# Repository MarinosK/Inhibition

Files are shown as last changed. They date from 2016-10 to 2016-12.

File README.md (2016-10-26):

### Inhibition ###

Installation | Workshop (c) 2016
by Marinos Koutsomichalis <marinos@marinoskoutsomichalis.com>

Code and hardware designs are distributed under the Attribution-NonCommercial-ShareAlike 3.0 Unported Creative Commons Licence (details here: http://creativecommons.org/licenses/by-nc-sa/3.0/deed.en_US).

> EVERYTHING IN THIS BUNDLE IS DISTRIBUTED AS IS WITH NO GUARANTEE OF FUNCTIONALITY OR RELEVANCE TO THIRD PARTY PROJECTS - THE DEVELOPER IS NOT TO BE HELD RESPONSIBLE FOR PERSONAL INJURIES, HARDWARE, FINANCIAL, OR ANY OTHER LOSSES AND IN GENERAL FOR ANY MISFORTUNATE EVENT CAUSED BY THE DESCRIBED SOFTWARE/HARDWARE OR IN THE PROCESS OF ATTEMPTING TO IMPLEMENT IT. IF YOU DON'T AGREE WITH THE AFOREMENTIONED YOUR ARE NOT ALLOWED TO USE THE MATERIAL PROVIDED HEREIN

# This bundle comprises #

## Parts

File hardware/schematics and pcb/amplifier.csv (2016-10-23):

Reference | Value | Footprint | Datasheet
R20 | 15K | Resistors_ThroughHole:Resistor_Horizontal_RM10mm
R19 | 10K | Resistors_ThroughHole:Resistor_Horizontal_RM10mm
C24 | .01μ | Capacitors_ThroughHole:C_Disc_D3_P2.5
C23 | .01μ | Capacitors_ThroughHole:C_Disc_D3_P2.5
C25 | 1n | Capacitors_ThroughHole:C_Disc_D3_P2.5
U4 | CA3140 | Housings_DIP:DIP-8_W7.62mm
C27 | 1μ | Capacitors_ThroughHole:C_Disc_D3_P2.5
C26 | 1μ | Capacitors_ThroughHole:C_Disc_D3_P2.5
C29 | 10μ | Capacitors_ThroughHole:C_Disc_D3_P2.5
C28 | 10μ | Capacitors_ThroughHole:C_Disc_D3_P2.5
R21 | 1K | Resistors_ThroughHole:Resistor_Horizontal_RM10mm
P7 | CONN_01X20 | Pin_Headers:Pin_Header_Straight_1x20
P6 | CONN_01X20 | Pin_Headers:Pin_Header_Straight_1x20
P4 | CONN_01X20 | Pin_Headers:Pin_Header_Straight_1x20
J1 | JACK_2P | Connect:BARREL_JACK
SW1 | Switch_DPST | Connect:Switch_LED
R5 | 100 | Resistors_ThroughHole:Resistor_Horizontal_RM10mm
R6 | 100 | Resistors_ThroughHole:Resistor_Horizontal_RM10mm
U1 | AD620 | Housings_DIP:DIP-8_W7.62mm
C7 | 0.01μ | Capacitors_ThroughHole:C_Disc_D3_P2.5
C8 | 0.33μ | Capacitors_ThroughHole:C_Disc_D3_P2.5
C11 | 0.01μ | Capacitors_ThroughHole:C_Disc_D3_P2.5
C12 | 0.33μ | Capacitors_ThroughHole:C_Disc_D3_P2.5
C9 | 0.01μ | Capacitors_ThroughHole:C_Disc_D3_P2.5
C5 | 0.01μ | Capacitors_ThroughHole:C_Disc_D3_P2.5
C10 | 0.33μ | Capacitors_ThroughHole:C_Disc_D3_P2.5
C6 | 0.33μ | Capacitors_ThroughHole:C_Disc_D3_P2.5
U2 | LM324 | Housings_DIP:DIP-14_W7.62mm
R4 | 100K | Resistors_ThroughHole:Resistor_Horizontal_RM10mm
C4 | 1n | Capacitors_ThroughHole:C_Rect_L7_W6_P5
C13 | 10μ | Capacitors_ThroughHole:C_Disc_D3_P2.5
R9 | 10K | Resistors_ThroughHole:Resistor_Horizontal_RM10mm
R12 | 470K | Resistors_ThroughHole:Resistor_Horizontal_RM10mm
R10 | 10K | Resistors_ThroughHole:Resistor_Horizontal_RM10mm
R14 | 10K | Resistors_ThroughHole:Resistor_Horizontal_RM10mm
C21 | 0.82μ | Capacitors_ThroughHole:C_Rect_L7_W6_P5
C17 | 0.47μ | Capacitors_ThroughHole:C_Rect_L7_W6_P5
R15 | 10K | Resistors_ThroughHole:Resistor_Horizontal_RM10mm
R17 | 470K | Resistors_ThroughHole:Resistor_Horizontal_RM10mm
C22 | 10μ | Capacitors_ThroughHole:C_Disc_D3_P2.5
R1 | 100K | Resistors_ThroughHole:Resistor_Horizontal_RM10mm
C3 | 1n | Capacitors_ThroughHole:C_Rect_L7_W6_P5
C2 | 0.01μ | Capacitors_ThroughHole:C_Rect_L7_W6_P5
R3 | 15M | Resistors_ThroughHole:Resistor_Horizontal_RM10mm
C1 | 0.01μ | Capacitors_ThroughHole:C_Rect_L7_W6_P5
R2 | 15M | Resistors_ThroughHole:Resistor_Horizontal_RM10mm
R16 | 10K | Resistors_ThroughHole:Resistor_Horizontal_RM10mm
R7 | 10K | Resistors_ThroughHole:Resistor_Horizontal_RM10mm
C16 | 0.82μ | Capacitors_ThroughHole:C_Rect_L7_W6_P5
C15 | 0.47μ | Capacitors_ThroughHole:C_Rect_L7_W6_P5
R11 | 10K | Resistors_ThroughHole:Resistor_Horizontal_RM10mm
R13 | 470K | Resistors_ThroughHole:Resistor_Horizontal_RM10mm
R8 | 10K | Resistors_ThroughHole:Resistor_Horizontal_RM10mm
C18 | 10μ | Capacitors_ThroughHole:C_Disc_D3_P2.5
C14 | 10μ | Capacitors_ThroughHole:C_Disc_D3_P2.5
P1 | CONN_01X03 | Pin_Headers:Pin_Header_Straight_1x03
RV1 | POT | Pin_Headers:Pin_Header_Angled_1x03
C19 | 0.01μ | Capacitors_ThroughHole:C_Disc_D3_P2.5
C20 | 0.33μ | Capacitors_ThroughHole:C_Disc_D3_P2.5
P8 | CONN_01X02 | Pin_Headers:Pin_Header_Straight_1x02
U3 | MCP3008 | Housings_DIP:DIP-16_W7.62mm
R18 | 220 | Resistors_ThroughHole:Resistor_Horizontal_RM10mm
P3 | CONN_01X07 | Pin_Headers:Pin_Header_Straight_1x07
P2 | CONN_01X07 | Pin_Headers:Pin_Header_Straight_1x07
P5 | CONN_01X20 | Pin_Headers:Pin_Header_Straight_1x20
R22 | 1K | Resistors_ThroughHole:Resistor_Horizontal_RM10mm

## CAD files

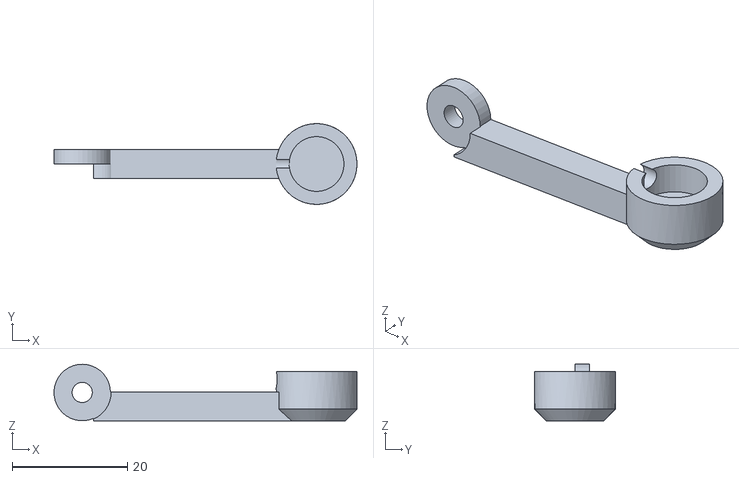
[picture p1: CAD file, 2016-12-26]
hardware/3d models/EEG Terminal Connectors/05.terminal.STL
52.5 x 14.0 x 9.79

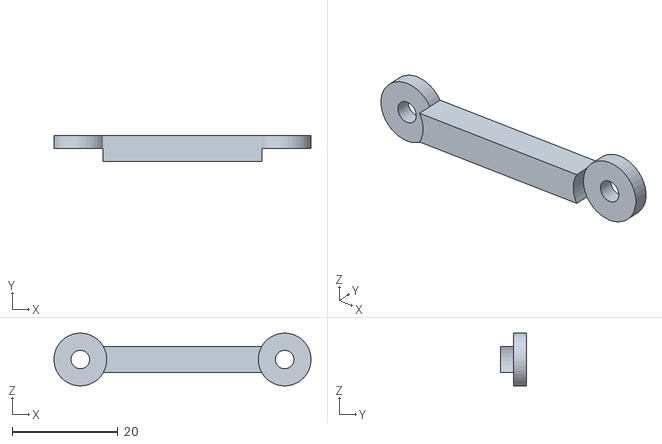
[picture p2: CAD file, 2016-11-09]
hardware/3d models/EEG Terminal Connectors/04.short_arm.STL
48.6 x 5.00 x 9.99

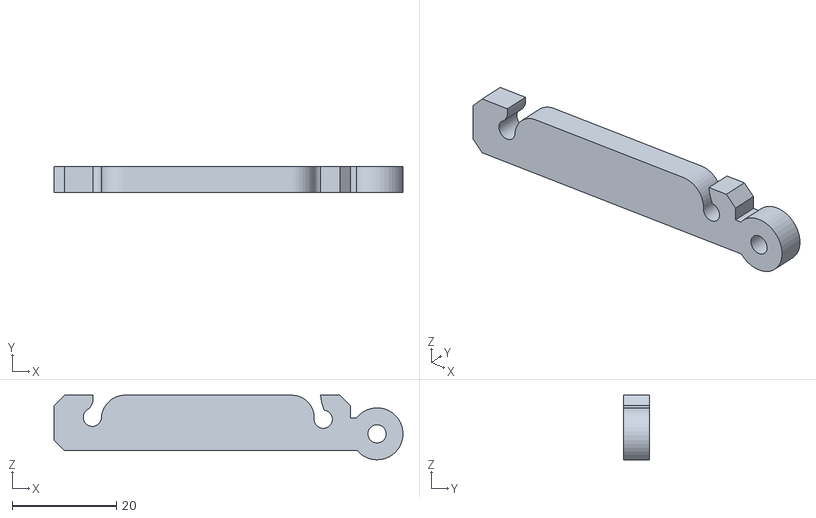
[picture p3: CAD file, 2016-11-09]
hardware/3d models/EEG Terminal Connectors/07.side_arm.STL
67.1 x 5.00 x 12.4

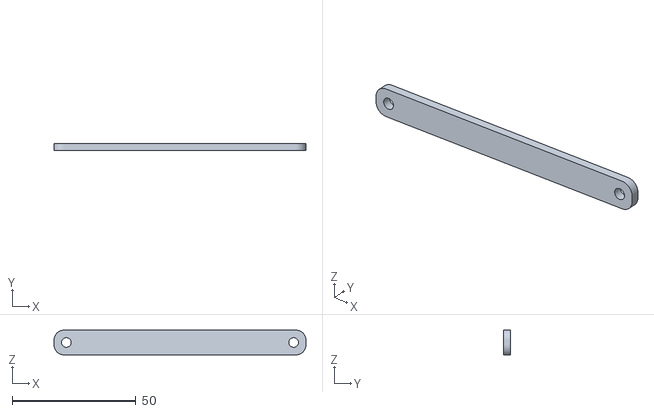
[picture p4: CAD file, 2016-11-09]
hardware/3d models/EEG Terminal Connectors/06.bridge.STL
102.0 x 3.00 x 10.0

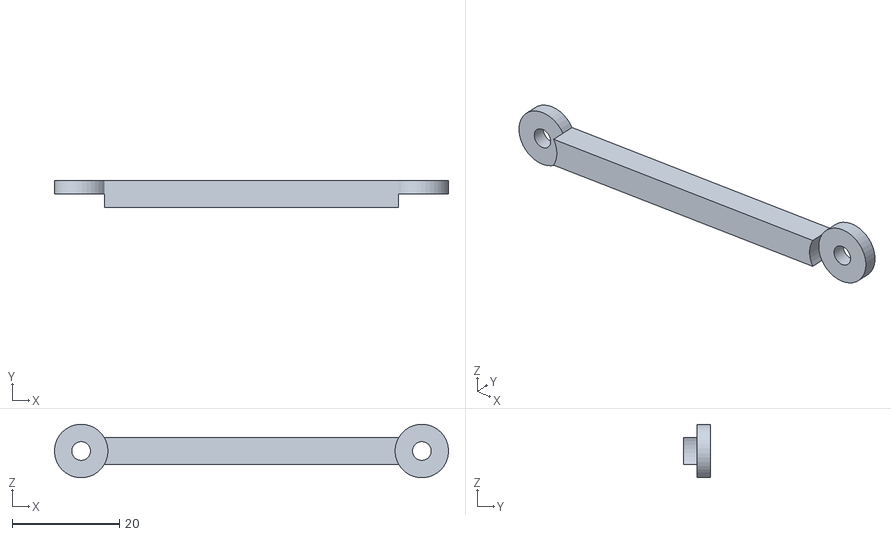
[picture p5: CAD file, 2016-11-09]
hardware/3d models/EEG Terminal Connectors/03.long_arm.STL
73.6 x 5.00 x 9.99

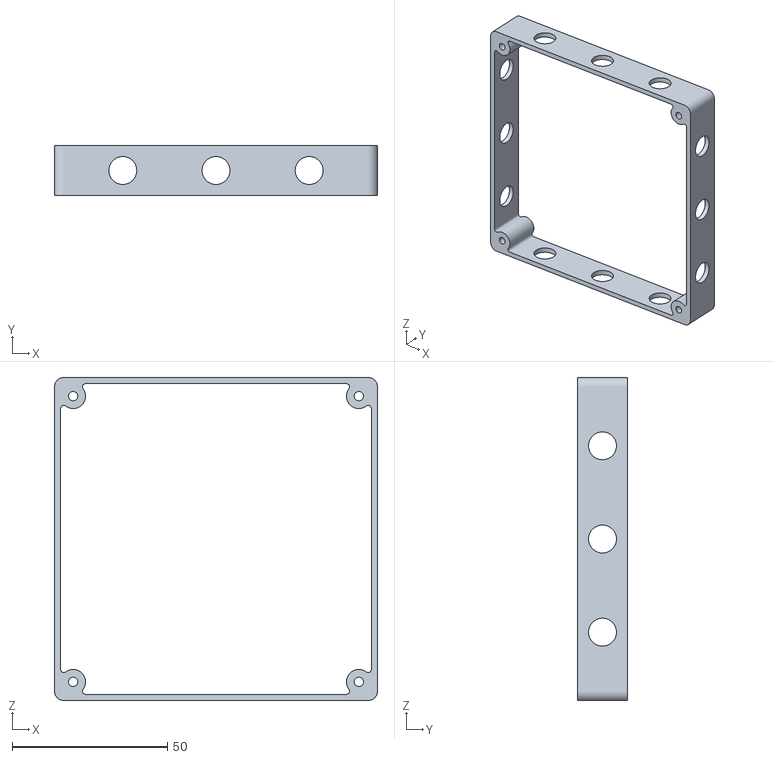
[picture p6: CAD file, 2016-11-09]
hardware/3d models/EEG Terminal Connectors/01.spacer.STL
104.0 x 16.0 x 104.0

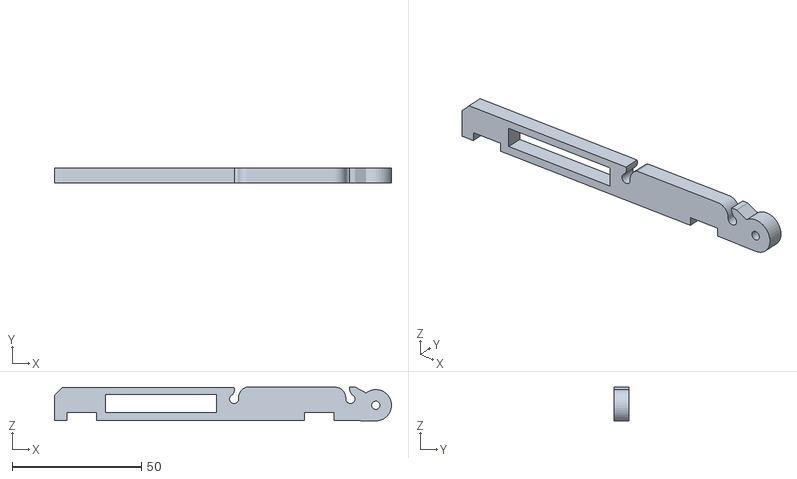
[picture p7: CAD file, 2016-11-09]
hardware/3d models/EEG Terminal Connectors/02.middle_arm.STL
130.5 x 6.00 x 13.1

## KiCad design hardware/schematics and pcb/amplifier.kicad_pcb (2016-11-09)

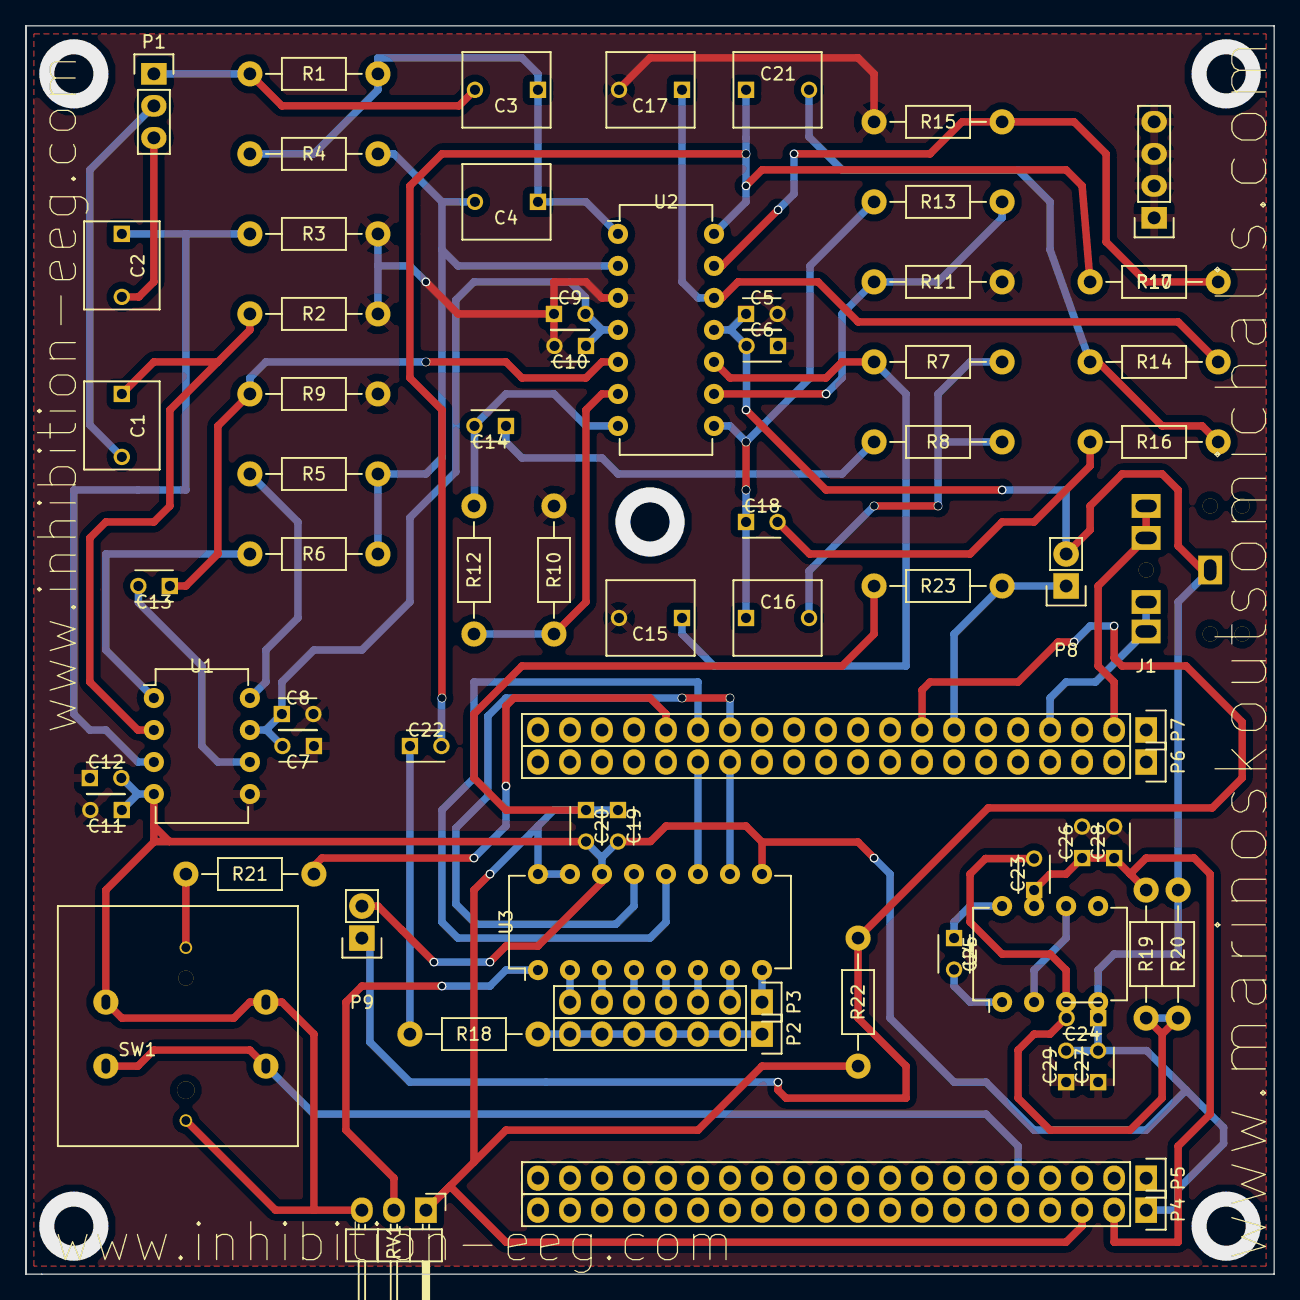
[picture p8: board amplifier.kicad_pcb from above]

Board: 2 copper layers, 99.1 x 99.1 mm, 69 parts (0 on the bottom side), 51 nets.

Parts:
C1, C2: 0.01μ; C_Rect_L7_W6_P5
C3, C4: 1n; C_Rect_L7_W6_P5
C5, C7, C9, C11, C19: 0.01μ; C_Disc_D3_P2.5
C6, C8, C10, C12, C20: 0.33μ; C_Disc_D3_P2.5
C13, C14, C18, C22, C28, C29: 10μ; C_Disc_D3_P2.5
C15, C17: 0.47μ; C_Rect_L7_W6_P5
C16, C21: 0.82μ; C_Rect_L7_W6_P5
C23, C24: .01μ; C_Disc_D3_P2.5
C25: 1n; C_Disc_D3_P2.5
C26, C27: 1μ; C_Disc_D3_P2.5
J1: JACK_2P; BARREL_JACK
P1: CONN_01X03; Pin_Header_Straight_1x03
P2, P3: CONN_01X07; Pin_Header_Straight_1x07
P4, P5, P6, P7: CONN_01X20; Pin_Header_Straight_1x20
P8, P9: CONN_01X02; Pin_Header_Straight_1x02
P10: CONN_01X04; Pin_Header_Straight_1x04
R1, R4: 100K; Resistor_Horizontal_RM10mm
R2, R3: 15M; Resistor_Horizontal_RM10mm
R5, R6, R18: 220; Resistor_Horizontal_RM10mm
R7, R8, R9, R10, R11, R14, R15, R16, R20: 10K; Resistor_Horizontal_RM10mm
R12: 890K; Resistor_Horizontal_RM10mm
R13: 1.8; Resistor_Horizontal_RM10mm
R17: .6; Resistor_Horizontal_RM10mm
R19: 15K; Resistor_Horizontal_RM10mm
R21: 10; Resistor_Horizontal_RM10mm
R22, R23: 1K; Resistor_Horizontal_RM10mm
RV1: POT; Pin_Header_Angled_1x03
SW1: Switch_DPST; Switch_LED
U1: AD620; DIP-8_W7.62mm
U2: LM324; DIP-14_W7.62mm
U3: MCP3008; DIP-16_W7.62mm
U4: CA3140; DIP-8_W7.62mm

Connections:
GND: C5.2, C6.1, C7.1, C8.2, C9.1, C10.2, C11.2, C12.1, C15.2, C17.2, C26.2, C27.1, C28.2, C29.1, P10.1, P10.2, P10.3, P10.4, R2.2, R3.2, R9.2, R10.2, R11.2, R15.2, U1.5, U2.3, U4.2, U4.6
unnamed: C1.1, R2.1, U1.2
unnamed: C1.2, P1.2
unnamed: C2.1, R3.1, U1.3
unnamed: C2.2, P1.3
unnamed: C3.1, C4.1, R1.1, R4.1, U2.1
unnamed: C3.2, P1.1, R1.2
unnamed: C4.2, R4.2, R5.2, R6.1, U2.2
unnamed: C13.1, R9.1, U2.5
unnamed: C13.2, U1.6
unnamed: C14.1, R8.2
unnamed: C14.2, R12.1, U2.7
unnamed: C15.1, R7.1, U2.10
unnamed: C16.1, C18.1, R13.1, U2.8
unnamed: C16.2, R7.2, R8.1
unnamed: C17.1, R14.2, U2.12
unnamed: C18.2, R16.2
unnamed: C19.1, C20.1, P4.3, R22.2, R23.2, RV1.1, U3.15, U3.16
unnamed: C21.1, C22.2, R17.1, U2.14
unnamed: C21.2, R14.1, R16.1
unnamed: C22.1, R18.1
unnamed: C23.2, C24.2, R19.2, R20.1, U4.3
unnamed: C25.1, U4.8
unnamed: C25.2, U4.1
unnamed: J1.1, P7.4
unnamed: J1.3, P7.2
unnamed: P2.1, P2.2, P2.3, P2.4, P2.5, P2.6, P2.7, R18.2
unnamed: P3.1, U3.8
unnamed: P3.2, U3.7
unnamed: P3.3, U3.6
unnamed: P3.4, U3.5
unnamed: P3.5, U3.4
unnamed: P3.6, U3.3
unnamed: P3.7, U3.2
unnamed: P5.5, SW1.1, SW1.3
unnamed: P6.14, U3.10
unnamed: P6.15, U3.11
unnamed: P7.7, P8.1, R23.1
unnamed: P7.8, P9.1, R22.1
unnamed: P7.14, U3.13
unnamed: P7.15, U3.12
unnamed: P7.16, R21.2
unnamed: R5.1, U1.8
unnamed: R6.2, U1.1
unnamed: R10.1, R12.2, U2.6
unnamed: R11.1, R13.2, U2.9
unnamed: R15.1, R17.2, U2.13
unnamed: R21.1, SW1.5
unnamed: RV1.2, U3.1
VCC: C7.2, C8.1, C9.2, C10.1, C23.1, C26.1, C28.1, P4.2, R19.1, U1.7, U2.4, U4.7
VEE: C5.1, C6.2, C11.1, C12.2, C19.2, C20.2, C24.1, C27.2, C29.2, J1.2, P4.1, P8.2, P9.2, R20.2, RV1.3, SW1.2, SW1.4, SW1.6, U1.4, U2.11, U3.9, U3.14, U4.4

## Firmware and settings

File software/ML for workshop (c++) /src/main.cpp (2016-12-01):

/*
 * by Marinos Koutsomichalis (me@marinoskoutsomichalis.com)
 * Heraklion, 10.2016
 * this program implements a neural network to use with the main SC code
 */

#include <fann.h>
#include <iostream>
#include <stdexcept>
#include <string>
#include <cstring>

// settings
const float desired_error = (const float) 0.01;
const unsigned int max_epochs = 10000;
const unsigned int epochs_between_reports = 100;

int main(int argc, char *argv[]) {
  try {
    if ( std::string(argv[1]) == "create") { // e.g. neural_net create
      unsigned int layers[5] = {8, 8, 24, 16, 8}; // the layers of the network
      struct fann *ann {fann_create_shortcut_array(5, layers)};
      fann_set_activation_function_hidden(ann, FANN_SIGMOID_SYMMETRIC);
      fann_set_activation_function_output(ann, FANN_SIGMOID_SYMMETRIC);
      fann_randomize_weights(ann,0,1);
      fann_save(ann, "network.net");
      fann_destroy(ann);
    } else if ( std::string(argv[1]) == "train") { // e.g. neural_net train data_file
      struct fann *ann  {fann_create_from_file("network.net")};
      fann_train_on_file(ann, argv[2], max_epochs, epochs_between_reports, desired_error);
      fann_save(ann, "network.net");
      fann_destroy(ann);
    } else if ( std::string(argv[1]) == "use") { // e.g. neural_net use 1 0 1 .. 1 (all the 16 features should be the input)
      struct fann *ann {fann_create_from_file("network.net")};
      fann_type input[8];
      for (int i=0; i<8; i++)
	input[i] = std::atof(argv[i+2]);
      fann_type *calc_out {fann_run(ann, input)};
      for (int i=0; i<8; i++)
	std::cout << calc_out[i] << ", ";
      std::cout << std::endl;
      fann_destroy(ann);
    }
    return 0;
  }
  catch (const std::runtime_error& e) {
    std::cerr << e.what() << std::endl;
    return 1;
  }
  catch (const std::exception& e) {
    std::cerr << e.what() << std::endl;
    return 2;
  }
  catch (...) {
    std::cerr << "uknown exception" << std::endl;
    return 3;
  }
}

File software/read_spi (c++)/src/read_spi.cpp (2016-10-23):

/*
 * by Marinos Koutsomichalis (me@marinoskoutsomichalis.com)
 * Heraklion, 10.2009
 * this program reads 2channels of 5seconds of eeg audio from a MPC3008 chip
 * and stores the output into an audio file
 */

#include "read_spi.h"

// static uint8_t mode {};
static uint16_t delay {};
static std::uint8_t bits {8};
static std::uint32_t speed {500000};
static const char* DEVICE {"/dev/spidev32766.0"};


int read_a_cycle(int fd, int line, int bil) {
  
  std::uint8_t tx[] = {1,0,0};
  std::uint8_t rx[] = {1,0,0};
  
  struct spi_ioc_transfer tr = {
    .tx_buf = (unsigned long) tx,
    .rx_buf = (unsigned long) rx,
    .len = ARRAY_SIZE(tx),
    .delay_usecs = delay,
    .speed_hz = speed,
    .bits_per_word = bits
  };

  tx[1] = ((bil & 1)?0x00:0x80) | ((line & 0x7)<< 4);
  int ret = ioctl(fd, SPI_IOC_MESSAGE(1), &tr); 

  if (ret < 1)
    throw std::runtime_error("didn't send spi message");
  
  return ((rx[1]&0x3)<<8)+rx[2];
}


std::vector<std::vector<int> > read_a_chunk() {

    int fd = open(DEVICE, O_RDWR);
    if (fd < 0) 
      throw std::runtime_error("didn't open device");
    
    constexpr unsigned int times = SAMPLE_RATE * BLOCK_SIZE_IN_SECONDS;
    constexpr unsigned int wait = 1000000 / SAMPLE_RATE;

    std::vector<std::vector<int> > data;
    wait_timer wt {std::chrono::microseconds(wait)};
    
    for (int j=0; j<times; j++) {
      std::vector<int> pair;
      for(int i=0; i<NUMBER_OF_CHANNELS_TO_READ; i++) 
	pair.emplace_back(read_a_cycle(fd,i+CHANNEL_OFFSET,0)); // eeg is on channels 2 and 3
      data.emplace_back(pair);
      wt.wait();
    }
    
    close(fd);

    return data;
}

int read_a_cycle_and_return(int channel) {

    int fd = open(DEVICE, O_RDWR);
    if (fd < 0) 
      throw std::runtime_error("didn't open device");
    
    int data {read_a_cycle(fd,channel,0)}; 
       
    close(fd);

    return data;
}

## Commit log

2016-10-23 first commit: software is more or less OK (I need to make it less CPU-expensive to avoid glitches and to add machine learning suppport), hardware the same (need to fix a couple of errors in the pcb a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
    [amplifier-B.Adhes.gbr, amplifier-B.CrtYd.gbr, amplifier-B.Cu.gbr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]
2016-10-26 updated the archicture so that I can now implement some ml algorithm - also minor changes elsewhere
    [amplifier.kicad_pcb, amplifier.sch]
2016-10-28 fine-tuning and minor changes
    [amplifier.sch]
2016-10-29 more minor changes and fine-tuning
    [amplifier.sch]
2016-11-09 fixed a couple of things in the pcb and added 3d models
    [01.spacer.STL, 02.middle_arm.STL, 03.long_arm.STL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]
2016-11-09 more fixes in the pcb
    [amplifier-B.Adhes.gbr, amplifier-B.CrtYd.gbr, amplifier-B.Cu.gbr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]
2016-11-11 corrected the set-up instructions
    [inhibition.gbl, inhibition.gbo, inhibition.gbs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]
2016-12-01 uses Pitch instead of Tartini
2016-12-01 corrected a couple of things in the set_up chip
2016-12-26 replaced a problematic 3d model
    [05.terminal.STL]
